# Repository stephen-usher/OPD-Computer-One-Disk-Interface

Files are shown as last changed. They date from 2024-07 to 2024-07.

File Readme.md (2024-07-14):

# The recreated Computer One floppy disk interface for the ICL One Per Desk.
## Version 1.0: 14th July, 2024.

This is a reverse engineered version of the Computer One floppy disk interface for the ICL One Per Desk.

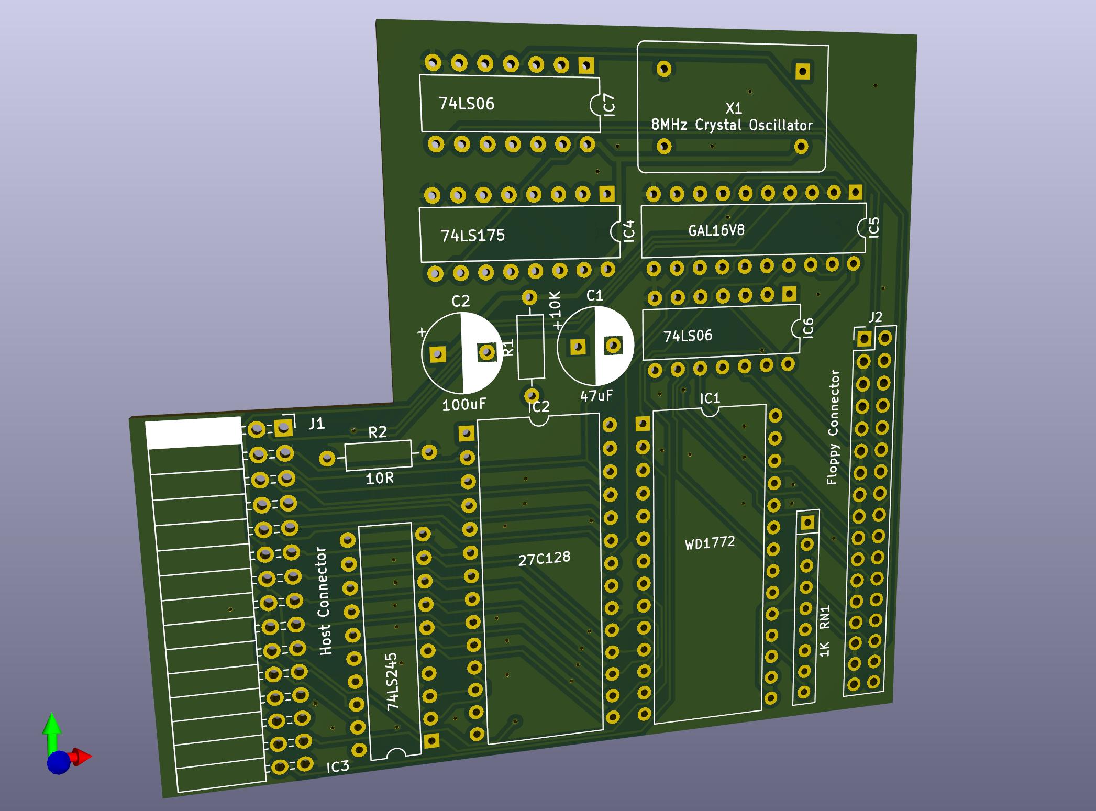
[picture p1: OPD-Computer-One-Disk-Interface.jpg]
Rendered image of circuit board


The circuitry has been simpified by replacing a great deal of discrete logic with a single GAL to handle the address decoding and the clock circuit has been replaced by a crystal oscillator.

The included ROM image also has beenmodified to add a BIOS Parameter Block to the boot sector on the floppy disk format so that MSDOS PCs and Atari STs can read it. Unfortunately if PCs try to write to the disk it will corrupt the format. In tests Atari STs can correctly write to the disks.

It should be noted that using the OPD Microdrive Utilities copy is hit and miss with Gotek drives for some reason. With real floppy disks it's fine.

If you wish to use EPROMs larger than a 27C128 use bodge wires to connect pins 1 and 27 of the ROM to ground or put multiple copies of the image onto the EPROM.

What you will need:

7 x 10nF 0805 ceramic capacitors (decoupling on rear).

1 x Right-angled 2.54mm pitch 15x2 header socket (female).

1 x 2.54mm pitch through hole 17x2 shrounded header.

2 x 74LS06

1 x 74LS245

1 x 74LS175

1 x 27C128 EPROM (or larger pin compatible EPROM or EEPROM)

1 x WD1772

1 x Microchip ATF16V8B GAL

1 x 8MHz crystal oscillator

1 x 100uF 16V radial electrolytic capacitor

1 x 47uF 16V radial electrolytic capacitor

1 x 9 pin 1K matrix resistor

1 x 10K 2W resistor

1 x 10 ohm 2W resistor

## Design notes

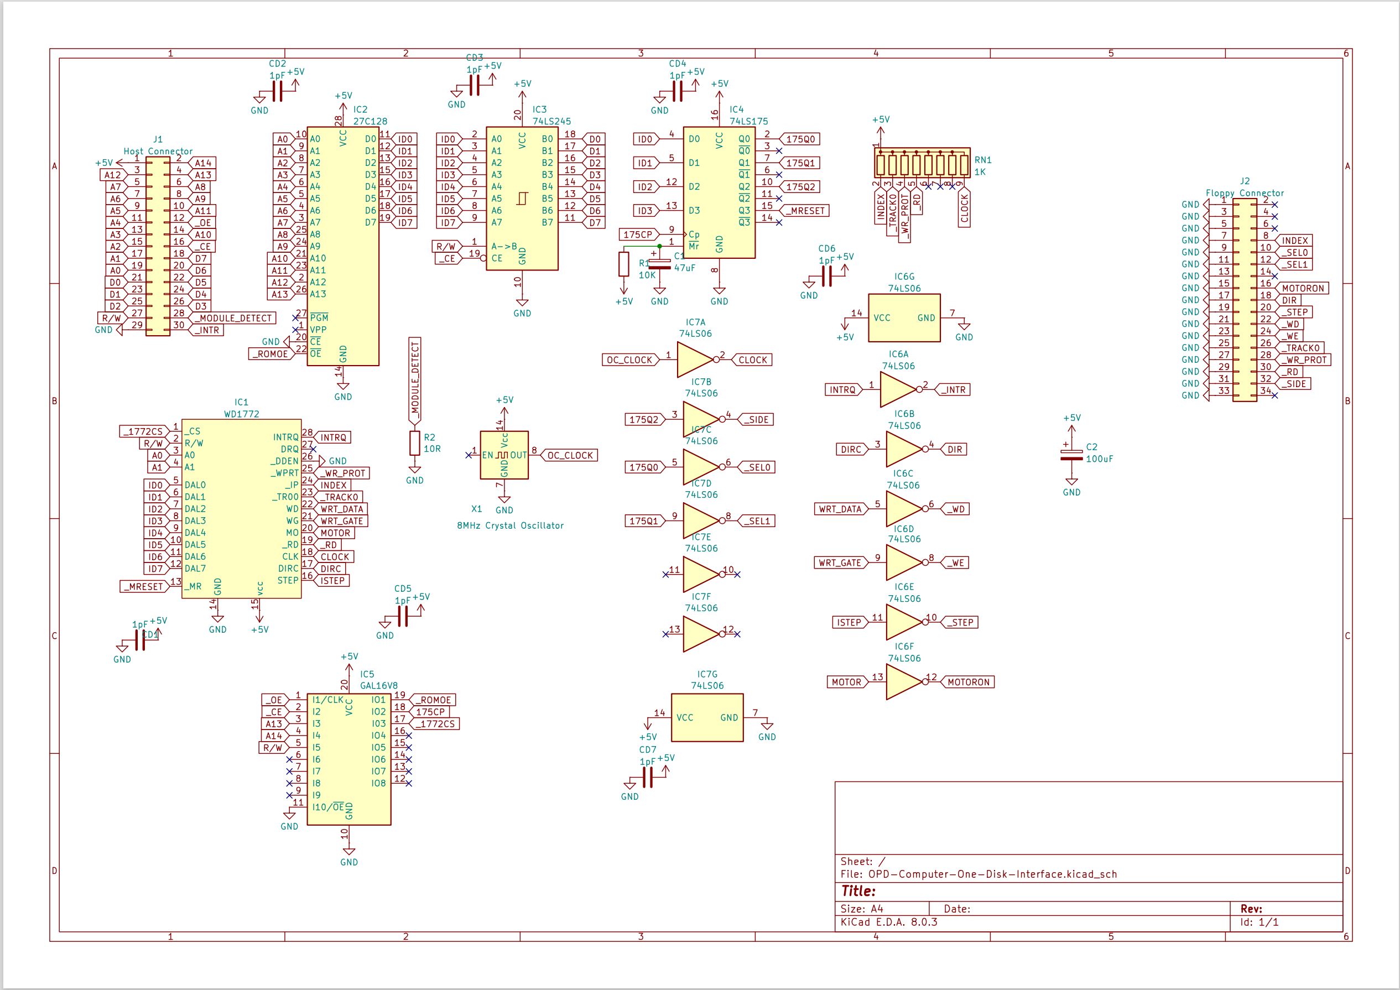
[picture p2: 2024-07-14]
OPD-Computer-One-Disk-Interface-schematic.jpg

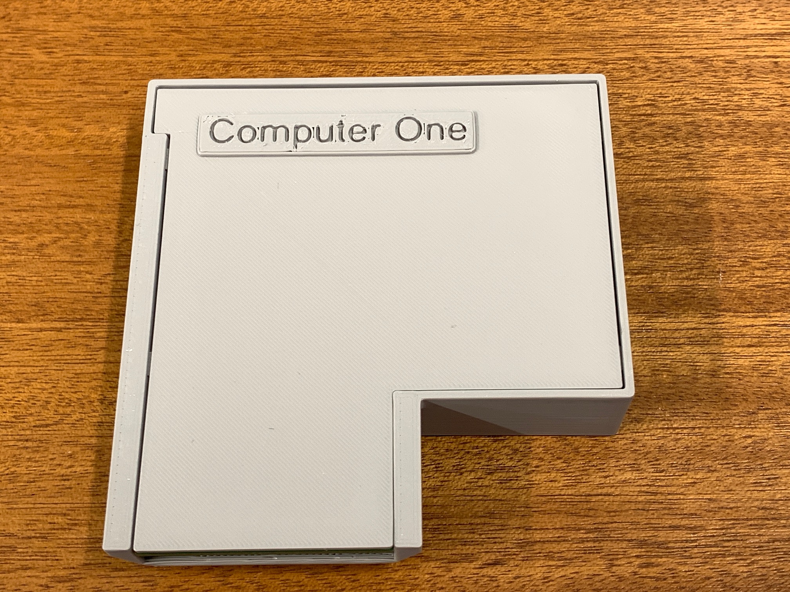
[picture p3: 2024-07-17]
Case/Case.jpg

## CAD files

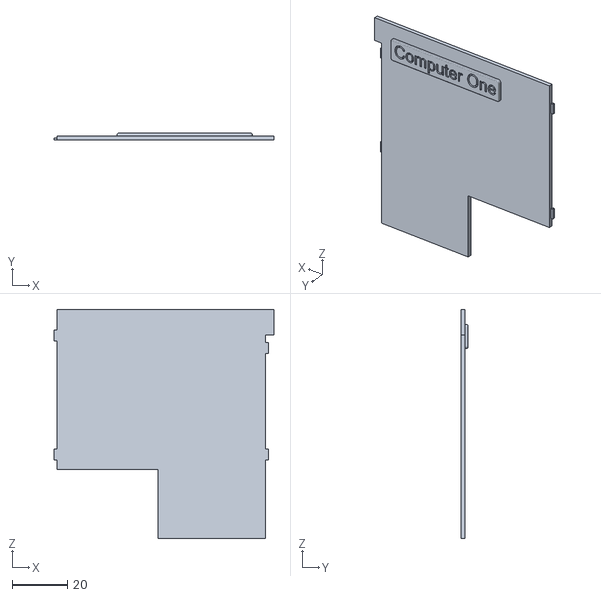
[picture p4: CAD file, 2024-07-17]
Case/Case-Front.stl
79.5 x 2.50 x 82.9

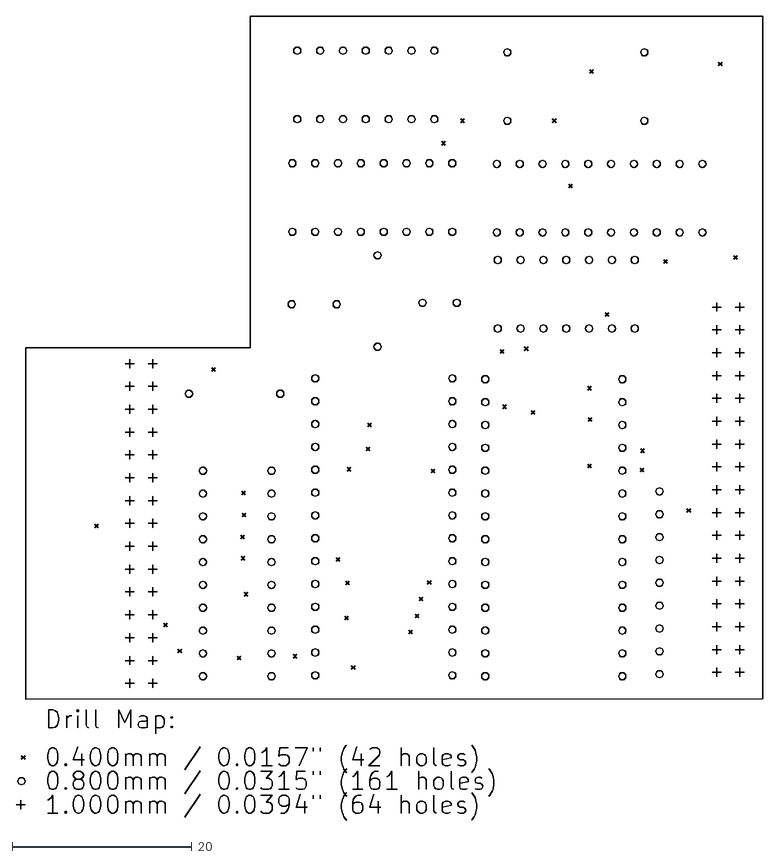
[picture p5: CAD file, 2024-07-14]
Gerbers/OPD-Computer-One-Disk-Interface-PTH-drl_map.dxf
83.1 x 89.4

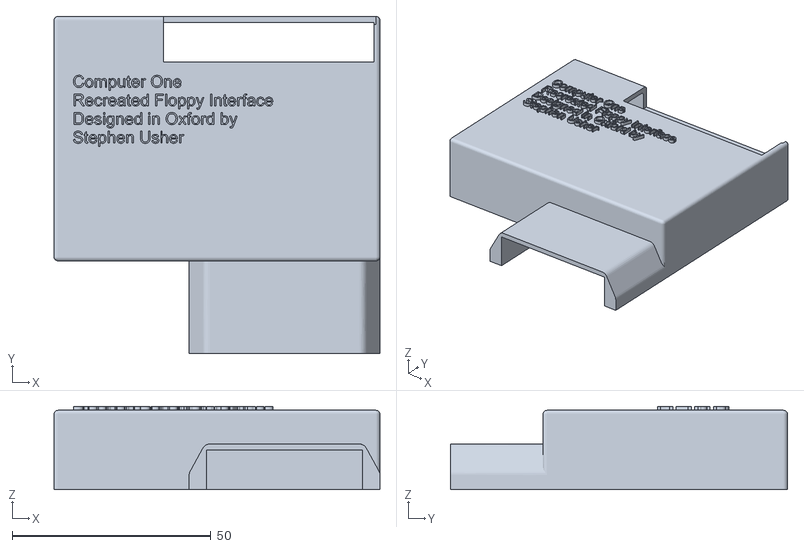
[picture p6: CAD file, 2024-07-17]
Case/Case-Rear.stl
82.0 x 84.8 x 21.0

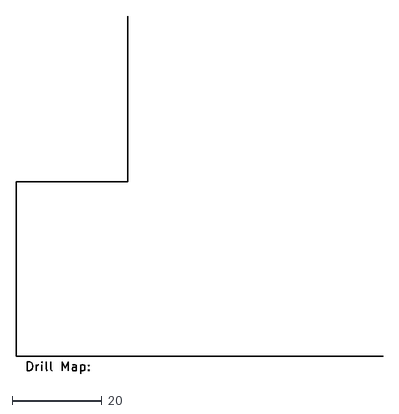
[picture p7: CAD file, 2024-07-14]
Gerbers/OPD-Computer-One-Disk-Interface-NPTH-drl_map.dxf
82.0 x 79.8

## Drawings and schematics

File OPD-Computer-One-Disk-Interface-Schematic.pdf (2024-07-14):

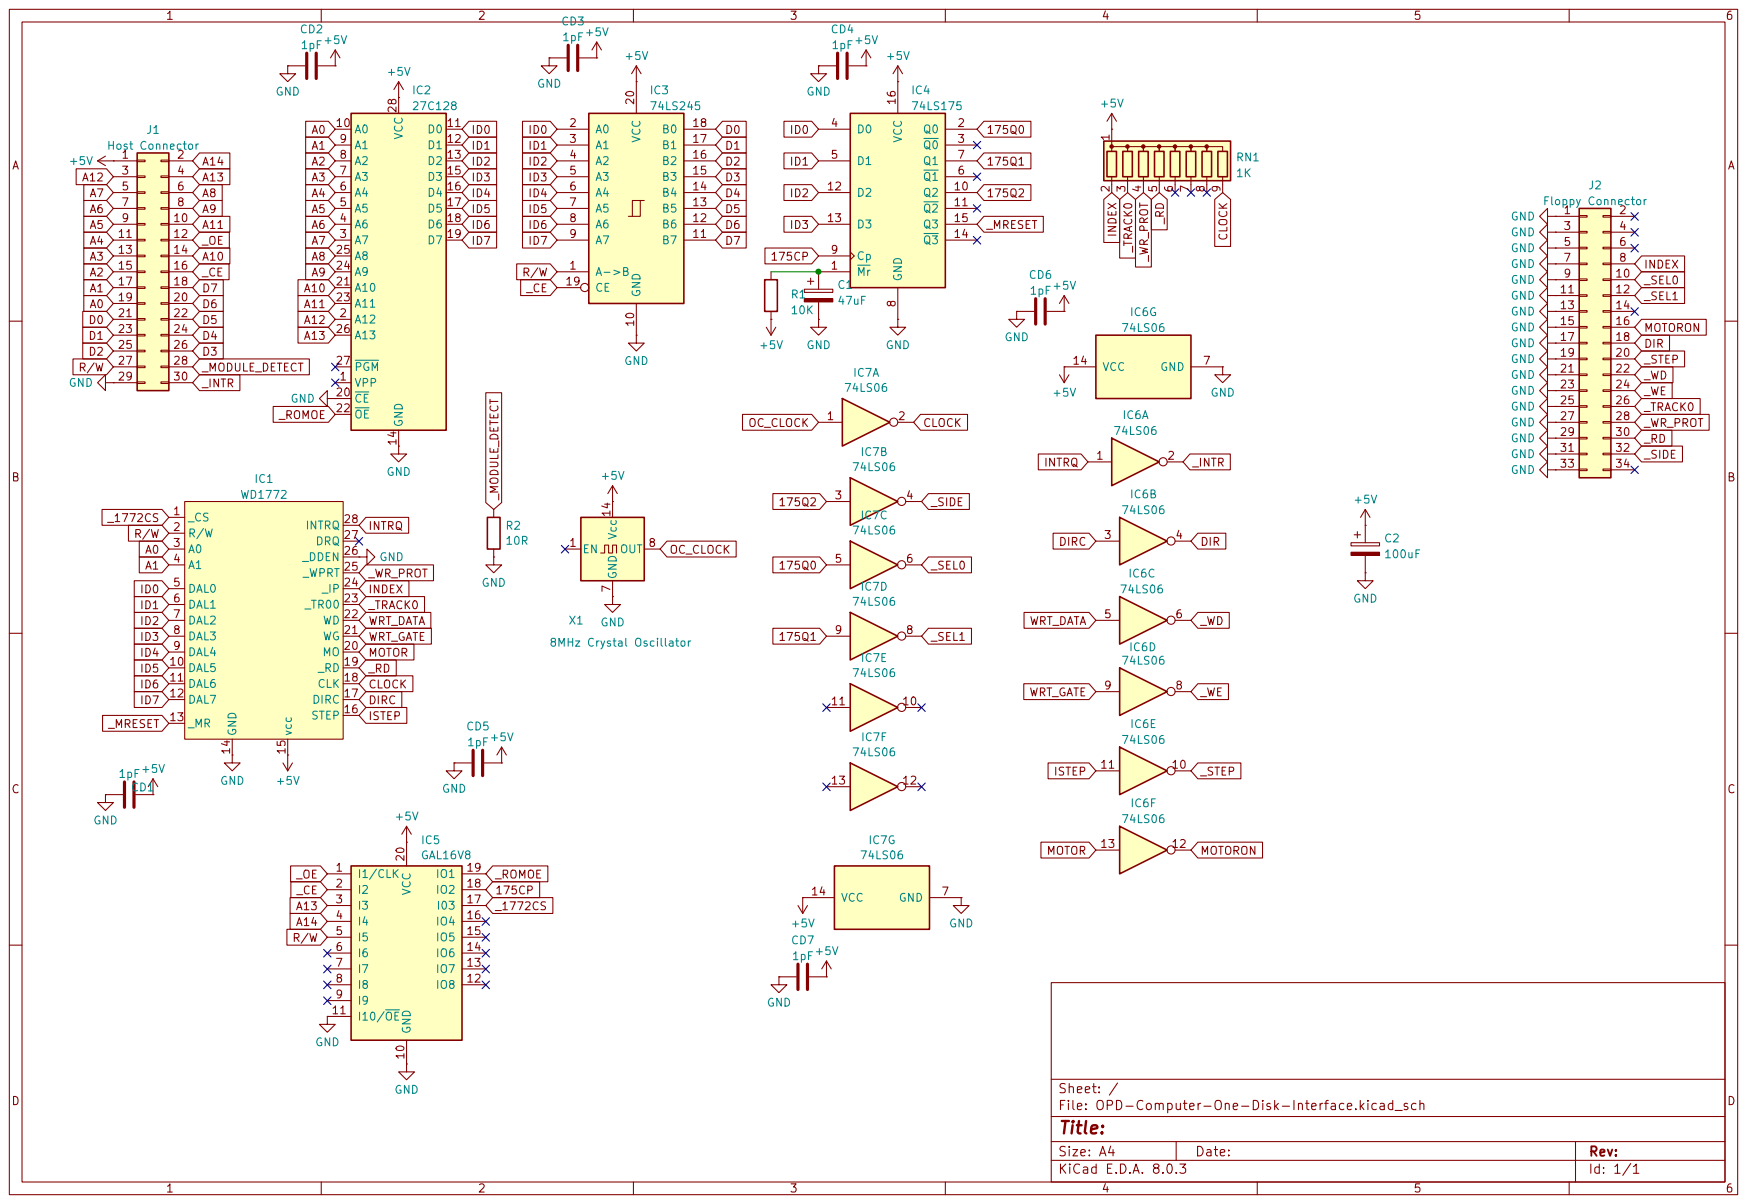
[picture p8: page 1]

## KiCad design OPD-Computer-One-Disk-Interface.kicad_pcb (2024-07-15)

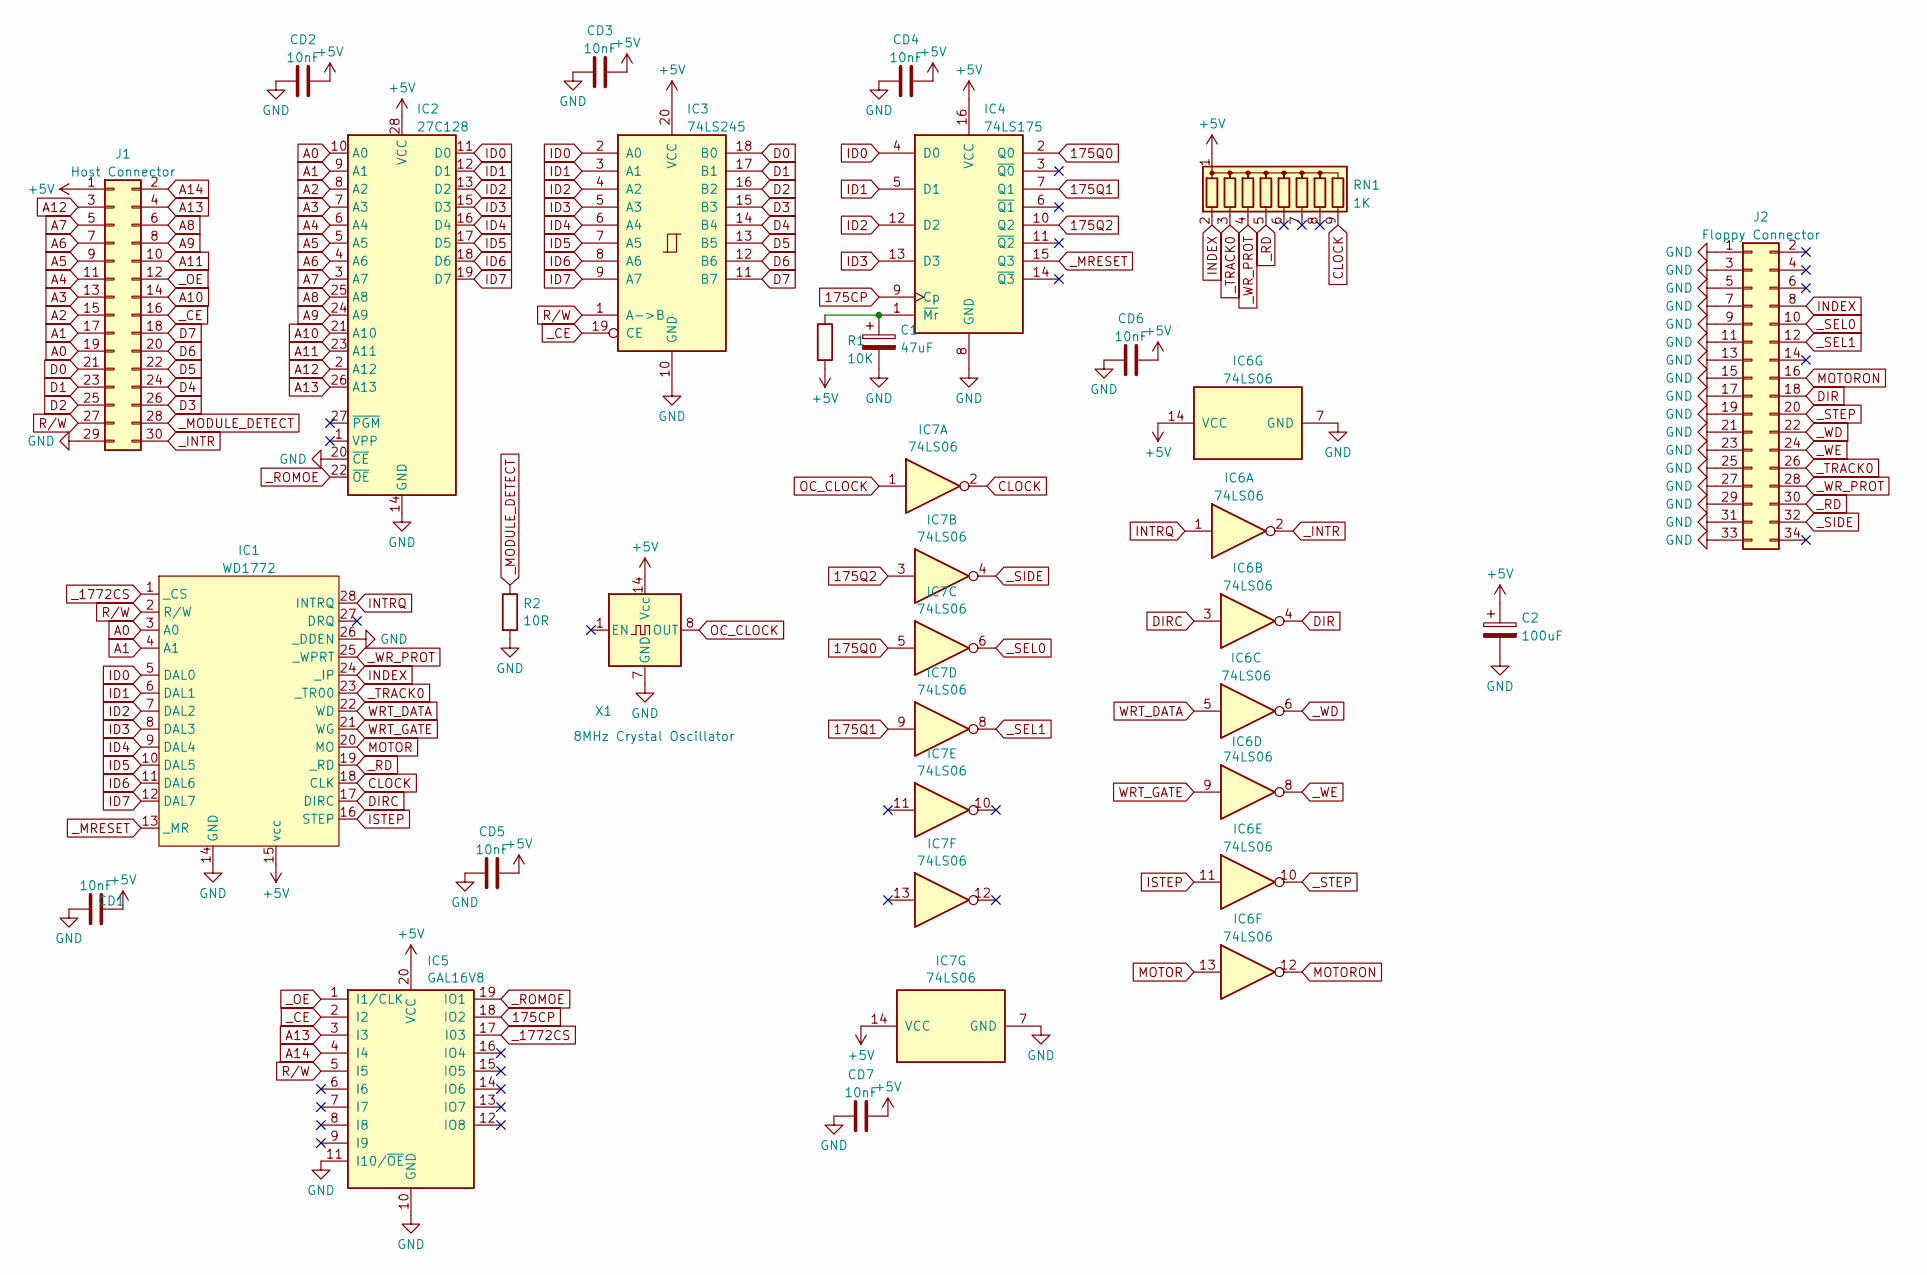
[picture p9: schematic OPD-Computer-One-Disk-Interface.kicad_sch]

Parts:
C1: 47uF; CP_Radial_D8.0mm_P3.80mm
C2: 100uF; CP_Radial_D8.0mm_P5.00mm
CD1, CD2, CD3, CD4, CD5, CD6, CD7: 10nF; C_0805_2012Metric_Pad1.18x1.45mm_HandSolder
IC1: WD1772; DIP-28_W15.24mm
IC2: 27C128; DIP-28_W15.24mm
IC3: 74LS245; DIP-20_W7.62mm
IC4: 74LS175; DIP-16_W7.62mm
IC5: GAL16V8; DIP-20_W7.62mm
IC6, IC7: 74LS06; DIP-14_W7.62mm
J1: Host Connector; PinSocket_2x15_P2.54mm_Horizontal
J2: Floppy Connector; PinHeader_2x17_P2.54mm_Vertical
R1: 10K; R_Axial_DIN0207_L6.3mm_D2.5mm_P10.16mm_Horizontal
R2: 10R; R_Axial_DIN0207_L6.3mm_D2.5mm_P10.16mm_Horizontal
RN1: 1K; R_Array_SIP9
X1: 8MHz Crystal Oscillator; Oscillator_DIP-14

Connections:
175CP: IC4.9 (Cp), IC5.18 (IO2)
175Q0: IC4.2 (Q0), IC7.5
175Q1: IC4.7 (Q1), IC7.9
175Q2: IC4.10 (Q2), IC7.3
+5V: C2.1, CD1.1, CD2.1, CD3.1, CD4.1, CD5.1, CD6.1, CD7.1, IC1.15 (vcc), IC2.28 (VCC), IC3.20 (VCC), IC4.16 (VCC), IC5.20 (VCC), IC6.14 (VCC), IC7.14 (VCC), J1.1, R1.2, RN1.1 (common), X1.14 (Vcc)
A0: IC1.3 (A0), IC2.10 (A0), J1.19
A1: IC1.4 (A1), IC2.9 (A1), J1.17
A2: IC2.8 (A2), J1.15
A3: IC2.7 (A3), J1.13
A4: IC2.6 (A4), J1.11
A5: IC2.5 (A5), J1.9
A6: IC2.4 (A6), J1.7
A7: IC2.3 (A7), J1.5
A8: IC2.25 (A8), J1.6
A9: IC2.24 (A9), J1.8
A10: IC2.21 (A10), J1.14
A11: IC2.23 (A11), J1.10
A12: IC2.2 (A12), J1.3
A13: IC2.26 (A13), IC5.3 (I3), J1.4
A14: IC5.4 (I4), J1.2
CLOCK: IC1.18 (CLK), IC7.2, RN1.9 (R8)
D0: IC3.18 (B0), J1.21
D1: IC3.17 (B1), J1.23
D2: IC3.16 (B2), J1.25
D3: IC3.15 (B3), J1.26
D4: IC3.14 (B4), J1.24
D5: IC3.13 (B5), J1.22
D6: IC3.12 (B6), J1.20
D7: IC3.11 (B7), J1.18
DIR: IC6.4, J2.18
DIRC: IC1.17 (DIRC), IC6.3
GND: C1.2, C2.2, CD1.2, CD2.2, CD3.2, CD4.2, CD5.2, CD6.2, CD7.2, IC1.14 (GND), IC1.26 (_DDEN), IC2.14 (GND), IC2.20 (~CE), IC3.10 (GND), IC4.8 (GND), IC5.10 (GND), IC5.11 (I10/~OE), IC6.7 (GND), IC7.7 (GND), J1.29, J2.1, J2.3, J2.5, J2.7, J2.9, J2.11, J2.13, J2.15, J2.17, J2.19, J2.21, J2.23, J2.25, J2.27, J2.29, J2.31, J2.33, R2.2, X1.7 (GND)
ID0: IC1.5 (DAL0), IC2.11 (D0), IC3.2 (A0), IC4.4 (D0)
ID1: IC1.6 (DAL1), IC2.12 (D1), IC3.3 (A1), IC4.5 (D1)
ID2: IC1.7 (DAL2), IC2.13 (D2), IC3.4 (A2), IC4.12 (D2)
ID3: IC1.8 (DAL3), IC2.15 (D3), IC3.5 (A3), IC4.13 (D3)
ID4: IC1.9 (DAL4), IC2.16 (D4), IC3.6 (A4)
ID5: IC1.10 (DAL5), IC2.17 (D5), IC3.7 (A5)
ID6: IC1.11 (DAL6), IC2.18 (D6), IC3.8 (A6)
ID7: IC1.12 (DAL7), IC2.19 (D7), IC3.9 (A7)
INDEX: IC1.24 (_IP), J2.8, RN1.2 (R1)
INTRQ: IC1.28 (INTRQ), IC6.1
ISTEP: IC1.16 (STEP), IC6.11
MOTOR: IC1.20 (MO), IC6.13
MOTORON: IC6.12, J2.16
unnamed: C1.1, IC4.1 (~Mr), R1.1
OC_CLOCK: IC7.1, X1.8 (OUT)
R/W: IC1.2 (R/W), IC3.1 (A->B), IC5.5 (I5), J1.27
WRT_DATA: IC1.22 (WD), IC6.5
WRT_GATE: IC1.21 (WG), IC6.9
_1772CS: IC1.1 (_CS), IC5.17 (I03)
_CE: IC3.19 (CE), IC5.2 (I2), J1.16
_INTR: IC6.2, J1.30
_MODULE_DETECT: J1.28, R2.1
_MRESET: IC1.13 (_MR), IC4.15 (Q3)
_OE: IC5.1 (I1/CLK), J1.12
_RD: IC1.19 (_RD), J2.30, RN1.5 (R4)
_ROMOE: IC2.22 (~OE), IC5.19 (IO1)
_SEL0: IC7.6, J2.10
_SEL1: IC7.8, J2.12
_SIDE: IC7.4, J2.32
_STEP: IC6.10, J2.20
_TRACK0: IC1.23 (_TR00), J2.26, RN1.3 (R2)
_WD: IC6.6, J2.22
_WE: IC6.8, J2.24
_WR_PROT: IC1.25 (_WPRT), J2.28, RN1.4 (R3)

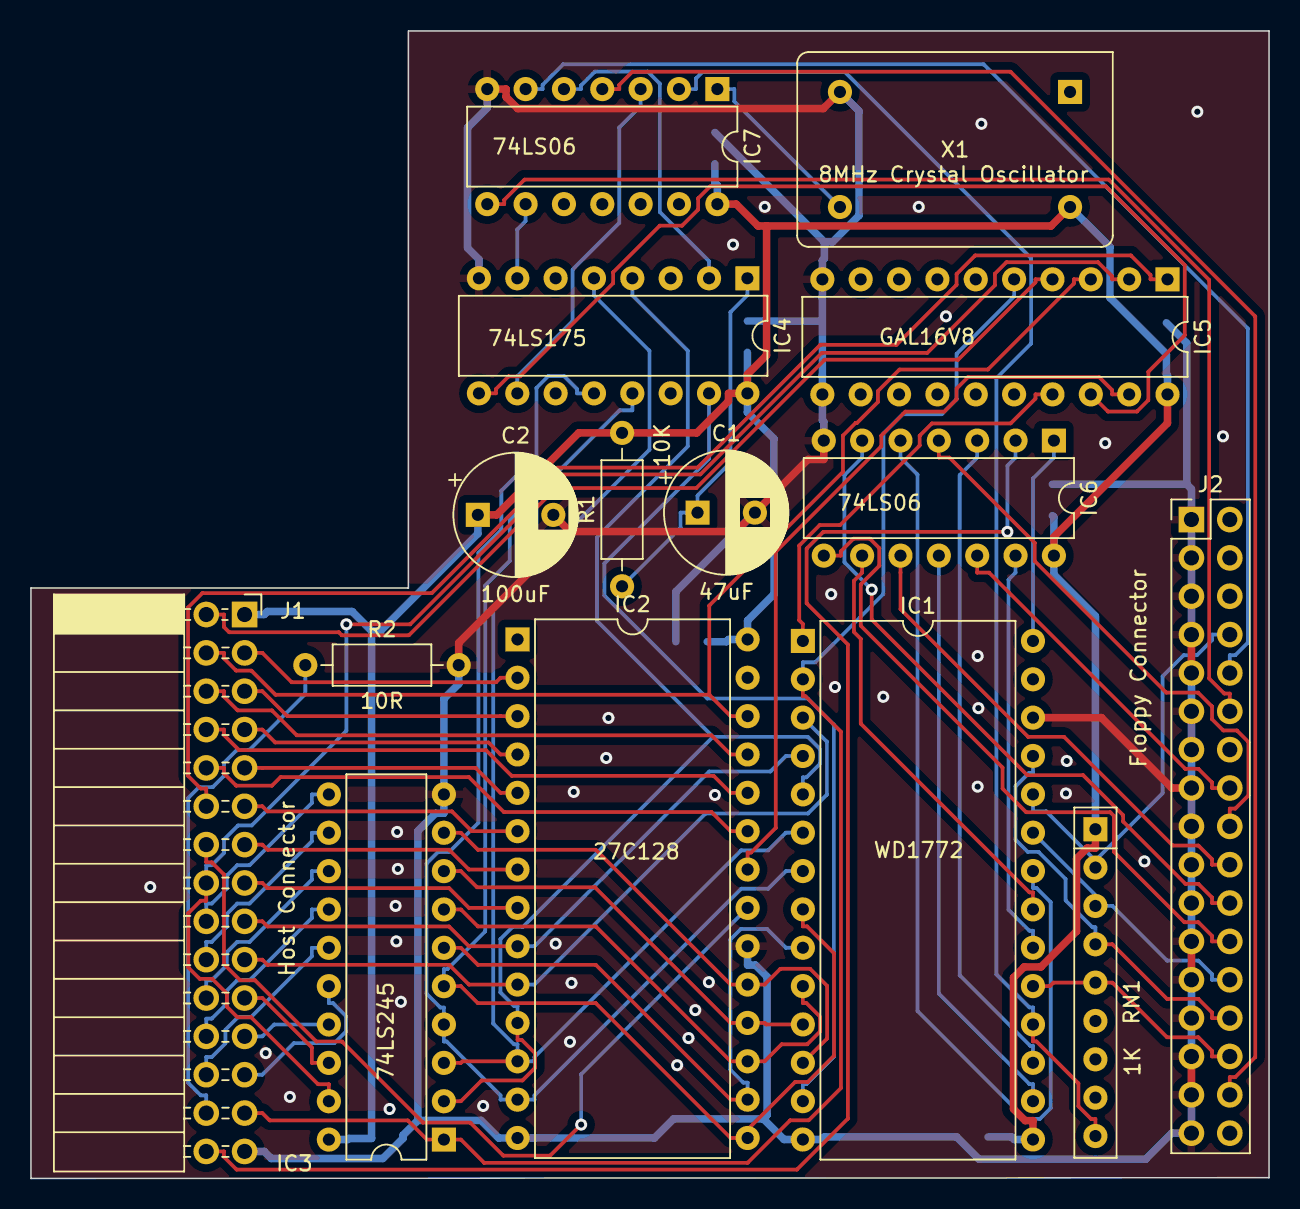
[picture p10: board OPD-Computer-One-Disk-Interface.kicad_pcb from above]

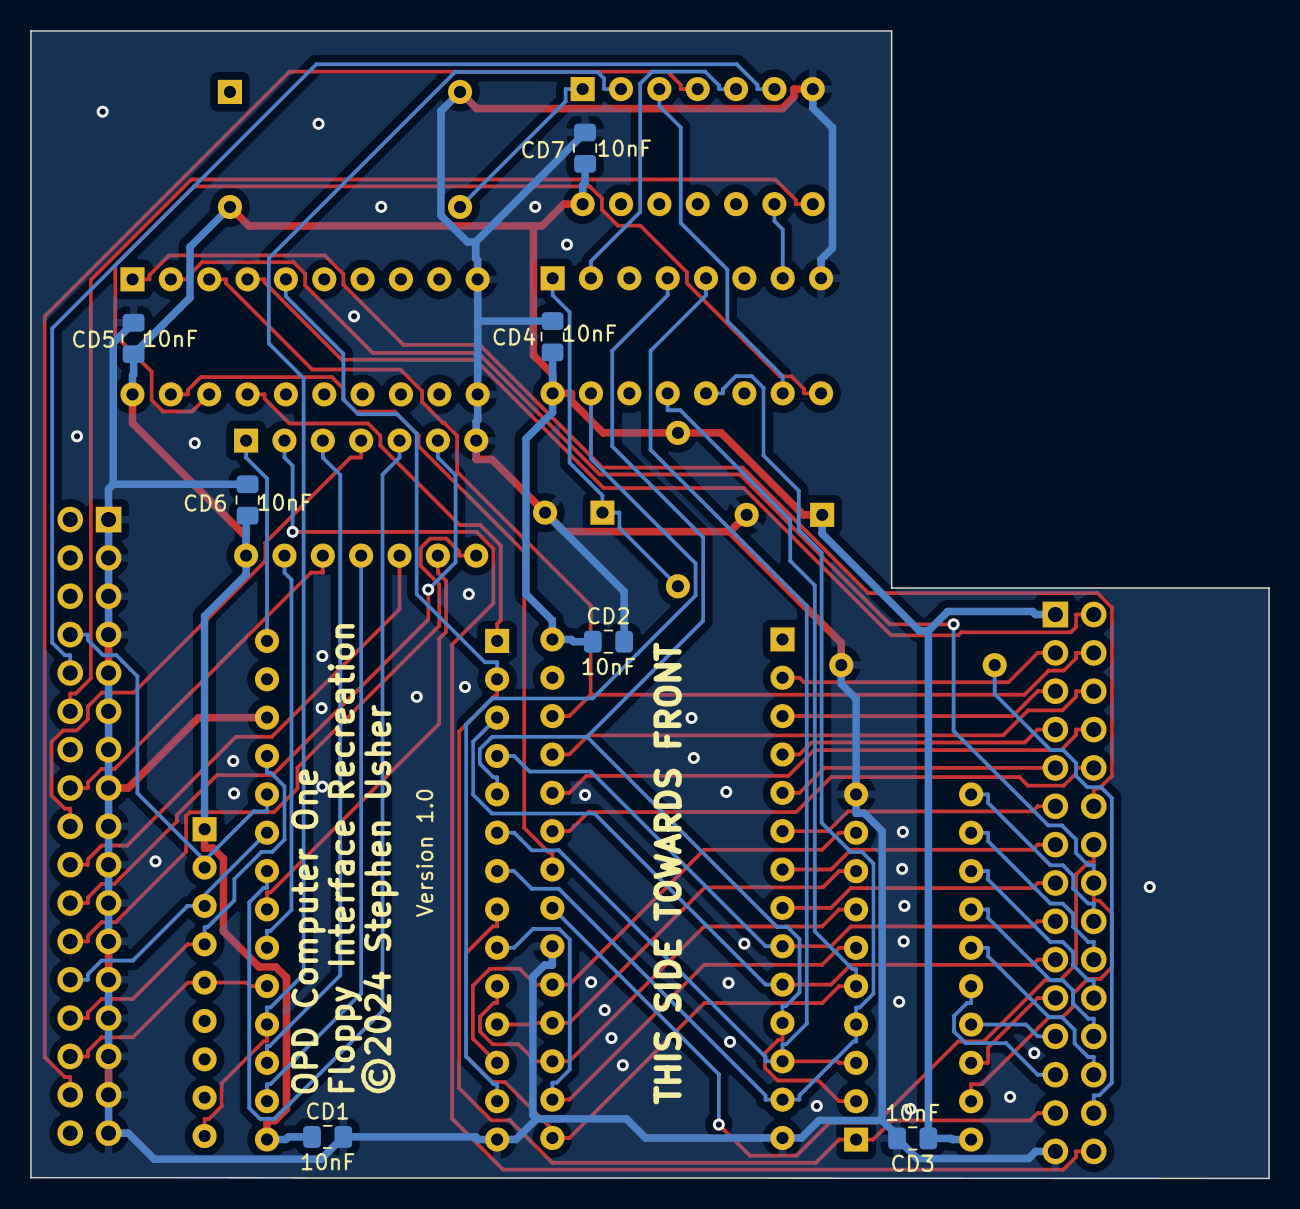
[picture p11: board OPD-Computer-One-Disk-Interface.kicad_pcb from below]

Board: 2 copper layers, 82.0 x 76.0 mm, 22 parts (7 on the bottom side), 66 nets.

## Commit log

2024-07-15 Fixed typo in copyright date on rear silkscreen.
    [OPD-Computer-One-Disk-Interface-B_Cu.gbr, OPD-Computer-One-Disk-Interface-B_Mask.gbr, OPD-Computer-One-Disk-Interface-B_Paste.gbr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]
2024-07-17 Added a 3D printed case.
    [Case-Front.stl, Case-Rear.stl]
2026-11-05 Fix stray memory write in the DOS-compatible driver ROM
    The DOS-compatible ROM changed 6 bytes at $1698-$169D to the text
    'C!/Add', overwriting the immediate value and the displacement of
    MOVE.L #imm,d16(A1) at $1696. The instruction then wrote 'C!/A' to
    A1+$6464, 26K past the driver's work area, on every catalogue read,
    instead of the volume marker 'ICL ' at +$18 of the catalogue header
    (a RAM-only record, never written to disc).
    Restore the original bytes 49 43 4C 20 00 18. The boot sector BPB
    template at $247E-$24A1 is unchanged, so discs stay PC and Atari
    readable. The unit header has no checksum.
    sha256 (32K): 23d522a36296f6329f47f6092e252fff84baa311a81ccca3e9c456660ad24594

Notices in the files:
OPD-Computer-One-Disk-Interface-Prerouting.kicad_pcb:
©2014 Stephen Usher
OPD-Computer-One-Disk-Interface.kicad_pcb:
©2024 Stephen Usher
